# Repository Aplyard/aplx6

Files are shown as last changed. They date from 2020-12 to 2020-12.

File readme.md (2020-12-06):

# Aplx6 (rev2)

Top View 
An updated encoder version, implementing music, browser and document shortcuts. Designed to be assembled as a sandwich with a blank PCB, using M2.5 screws and spacers, your choice of MX- or Alps-compatible switches, and 1N4148 diodes.
## New features
* Encoder (with push button for cycling layers)
* Oled display for some fancy logos
* More layers

## New Layout  
|Default|Layer|(0)|
|--|--|--|
| Mute|Play|Fn & Vol +/-|
|Prev|Stop|Next|

<br />

| Fn |Layer|(1)
|--|--|--|
|Home|PgUp|Cursor|
|End|PgDown|Ins

<br />

| Fn |Layer|(2)
|--|--|--|
|Calc|MyPc|Brightness|
|Copy|Cut|Paste

## Firmware
Aplx6 uses [QMK Firmware](https://qmk.fm/)  
 
Make example for this keyboard (after setting up your build environment):

     make aplyard/aplx6/rev2:default

See the [build environment setup](https://docs.qmk.fm/#/getting_started_build_tools) and the [make instructions](https://docs.qmk.fm/#/getting_started_make_guide) for more information. Brand new to QMK? Start with our [Complete Newbs Guide](https://docs.qmk.fm/#/newbs).

## Info
* Keyboard Maintainer: [Aplyard](https://github.com/Aplyard)
* Hardware Supported: Aplx6 rev2 PCB, Pro Micro (ATmega32U4)
* Hardware Availability: [GitHub](https://github.com/Aplyard/Aplx6-rev2)

---  

****Designed in**:**  
[KiCad](https://github.com/KiCad)  

**Components Footprints & Libraries :**  
[MX_Alps_Hybrid](https://github.com/tyetye/MX_Alps_Hybrid.pretty)  
[keebs.pretty](https://github.com/egladman/keebs.pretty)  
[keyboard_parts.pretty
](https://github.com/tmk/keyboard_parts.pretty)  
[ProMicro KiCad](https://github.com/Biacco42/ProMicroKiCad) 

**Usefull Links:**  
[Qmk Online Configurator](https://config.qmk.fm/#)  
[Keyboard Layout Editor](http://www.keyboard-layout-editor.com/#/)   
[Keyboard Plate & Case Builder](http://builder.swillkb.com/)

---

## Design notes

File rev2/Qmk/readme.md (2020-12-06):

# Aplx6 rev2

Top View 
   
An updated encoder version, implementing music, browser and document shortcuts. Designed to be assembled as a sandwich with a blank PCB, using M2.5 screws and spacers, your choice of MX- or Alps-compatible switches, and 1N4148 diodes.

## New features
* Encoder (with push button for cycling layers)
* Oled display for some fancy logos
* More layers

## Firmware
* Keyboard Maintainer: [Aplyard](https://github.com/Aplyard)
* Hardware Supported: Aplx6 PCB, Pro Micro (ATmega32U4)
* Hardware Availability: [GitHub](https://github.com/Aplyard/aplx6/tree/master/rev2)

Make example for this keyboard (after setting up your build environment):

     make aplyard/aplx6/rev2:default

See the [build environment setup](https://docs.qmk.fm/#/getting_started_build_tools) and the [make instructions](https://docs.qmk.fm/#/getting_started_make_guide) for more information. Brand new to QMK? Start with our [Complete Newbs Guide](https://docs.qmk.fm/#/newbs).

---  
****Designed in**:**  
[KiCad](https://github.com/KiCad)  

**Components Footprints & Libraries :**  
[MX_Alps_Hybrid](https://github.com/tyetye/MX_Alps_Hybrid.pretty)  
[keebs.pretty](https://github.com/egladman/keebs.pretty)  
[keyboard_parts.pretty
](https://github.com/tmk/keyboard_parts.pretty)  
[ProMicro KiCad](https://github.com/Biacco42/ProMicroKiCad) 

**Usefull Links:**  
[Qmk Online Configurator](https://config.qmk.fm/#)  
[Keyboard Layout Editor](http://www.keyboard-layout-editor.com/#/)   
[Keyboard Plate & Case Builder](http://builder.swillkb.com/)

---

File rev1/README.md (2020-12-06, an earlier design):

# Aplx6
https://github.com/Aplyard/aplx6   
   
A stylish (2x3) 6-key MediaPad for your music and browser shortcuts.
Designed to be assembled as a sandwich with a blank pcb, using m2.5 screws and spacers. 
Diodes : 1N4148   

---

FrontEmpty   

Back

Front

---

**Can support Rgb underglow (WS2812)** 

Just wire them to any of the unused ProMicro pins.
Don't forget to edit-uncomment the [config.h](https://github.com/Aplyard/Aplx6/blob/master/qmk/config.h) and the [rules.mk](https://github.com/Aplyard/Aplx6/blob/master/qmk/rules.mk)
for RGB underglow support or even add your own functions and modes.
Used pins can be found in [config.h](https://github.com/Aplyard/Aplx6/blob/master/qmk/config.h) or in the [KiCad Schematic](https://github.com/Aplyard/Aplx6/blob/master/kiCad/xd6.sch)
All ProMicro pins can be found [here](https://golem.hu/article/pro-micro-pinout/) along with the +2 pins mod.

---

**Default Keymap Layout is [Media](https://github.com/Aplyard/Aplx6/blob/master/qmk/keymaps/Media/keymap.c)** (no RGB shortcuts)

|Default|Layer|(0)|
|--|--|--|
| Play|VolUp|Fn|
|Prev|VolDown|Next|

=========================
| Fn |Layer|(1)
|--|--|--|
|Calc|PgUp|KC_TRANS|
|MyPc|PgDown|RESET

---

Make example for this keyboard (after setting up your build environment):

     make aplyard/aplx6/rev1:default

See [build environment setup](https://docs.qmk.fm/#/getting_started_build_tools) then the [make instructions](https://docs.qmk.fm/#/getting_started_make_guide) for more information.

---  
****Designed in**:**  
[KiCad](https://github.com/KiCad)  

**Components Footprints & Libraries :**  
[keebs.pretty](https://github.com/egladman/keebs.pretty)  
[keyboard_parts.pretty
](https://github.com/tmk/keyboard_parts.pretty)  
[ProMicro KiCad](https://github.com/Biacco42/ProMicroKiCad)  

**Usefull Links:**  
[Qmk Online Configurator](https://config.qmk.fm/#)  

**Alternatives of qmk that worked for me:**  
[Keyboard Layout Editor](http://www.keyboard-layout-editor.com/#/)   
[Keyboard Plate & Case Builder](http://builder.swillkb.com/)  
[Firmware Builder](https://kbfirmware.com/)      

---   
Keyboard Maintainer: Aplyard  
Hardware Supported: Pro Micro ATmega32U4  
Hardware Availability: Aplyard

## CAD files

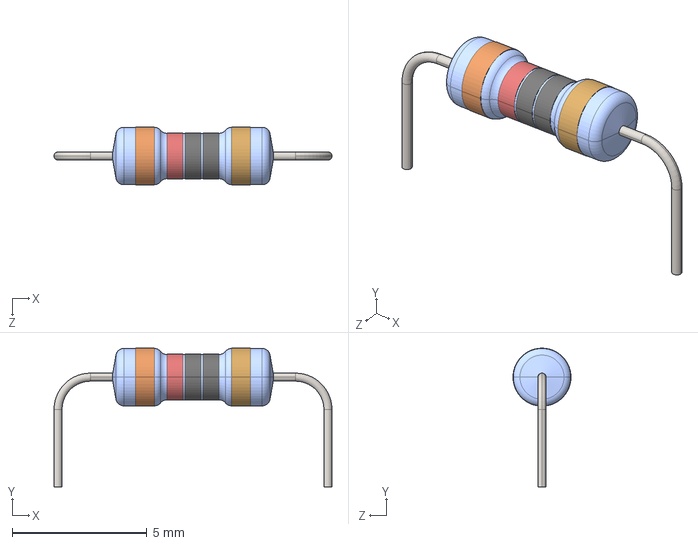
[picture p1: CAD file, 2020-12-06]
rev2/Pcb/3dModels/axial resistor 6mm.STEP
10.3 x 5.14 x 2.15 mm

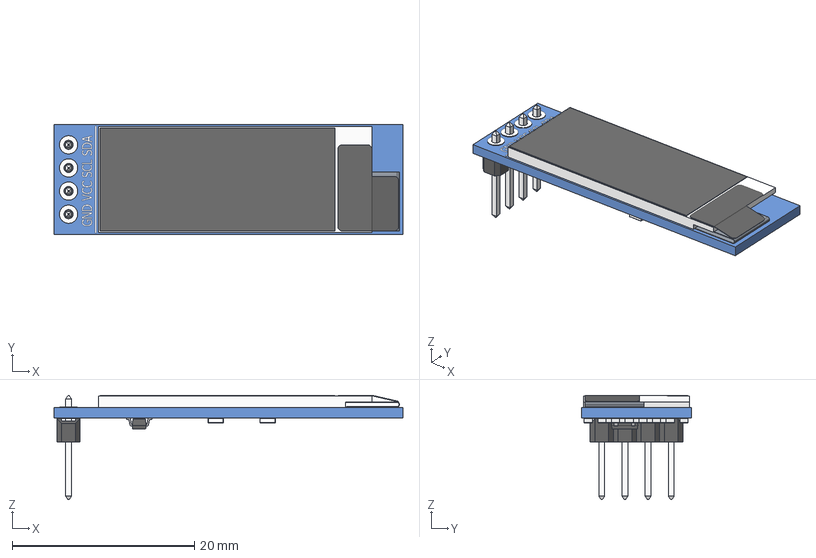
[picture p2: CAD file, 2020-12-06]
rev2/Pcb/3dModels/OLED_0.91_128x32.stp
38.3 x 12.1 x 11.5 mm
OLED_0.91_128x32
Pin Header 4 x 1 TH 2.54mm Pitch
RESC-0603 x 13
2SD0601A

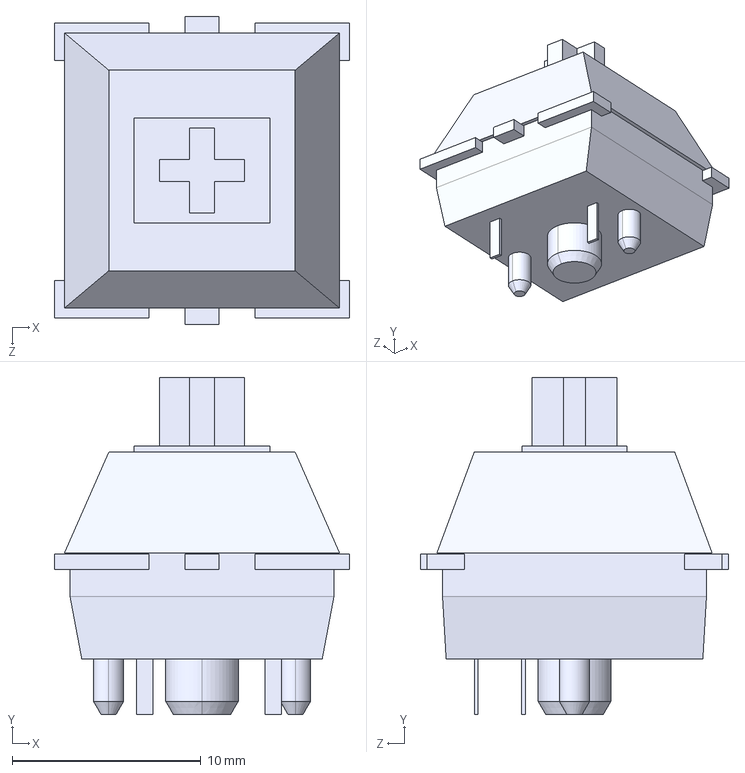
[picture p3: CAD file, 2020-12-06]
rev2/Pcb/3dModels/cherry mx.STEP
15.6 x 17.9 x 16.3 mm

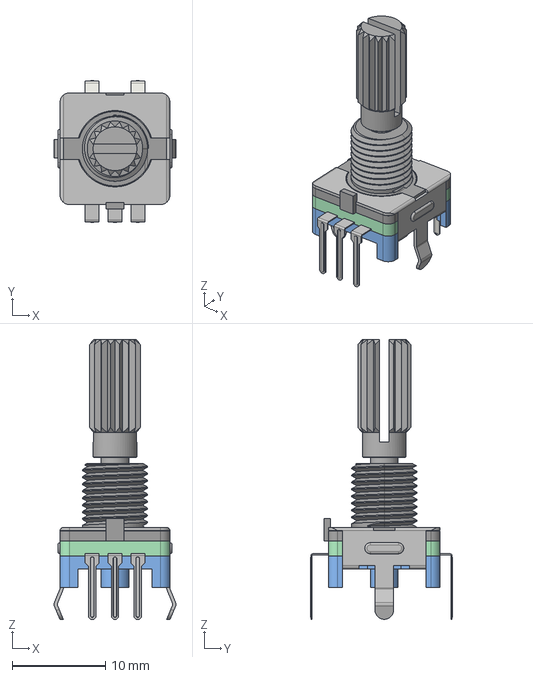
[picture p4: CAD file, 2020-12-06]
rev2/Pcb/3dModels/EC11_Rotary_Encoder_Switched.step
13.1 x 15.3 x 30.1 mm

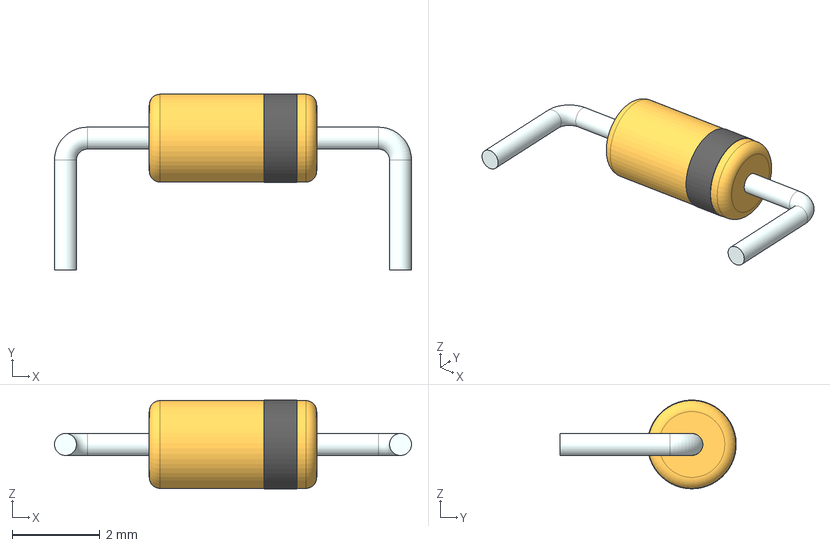
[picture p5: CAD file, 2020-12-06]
rev2/Pcb/3dModels/Diode DO-35 300 mil.step
8.12 x 4.01 x 2.02 mm

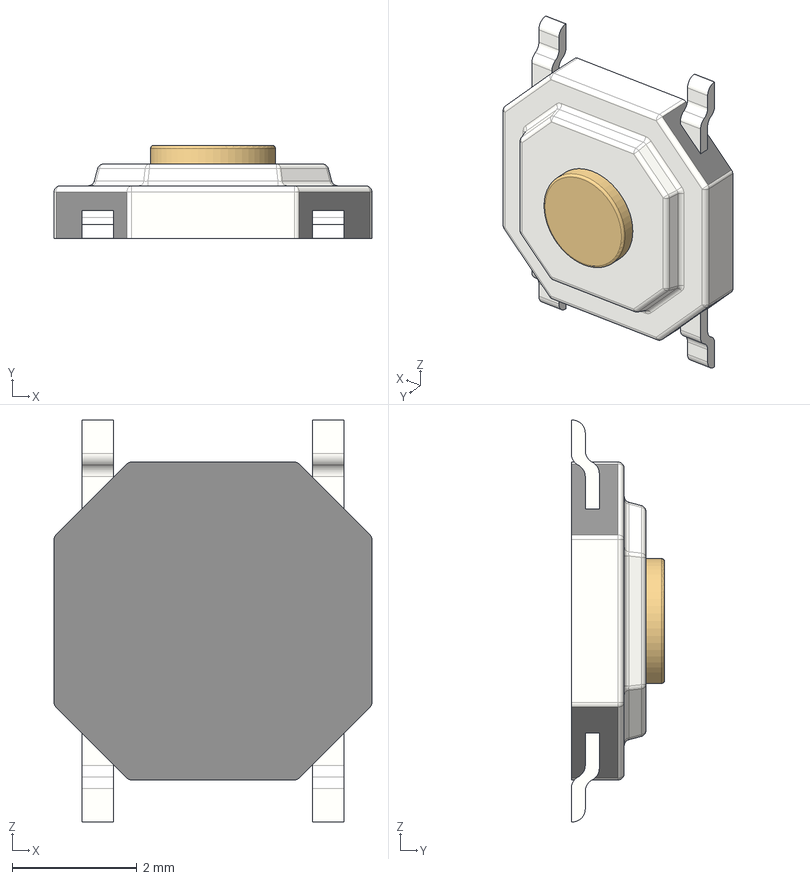
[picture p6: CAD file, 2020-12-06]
rev2/Pcb/3dModels/TactileButton(5mm)_SMD.stp
5.10 x 1.50 x 6.45 mm

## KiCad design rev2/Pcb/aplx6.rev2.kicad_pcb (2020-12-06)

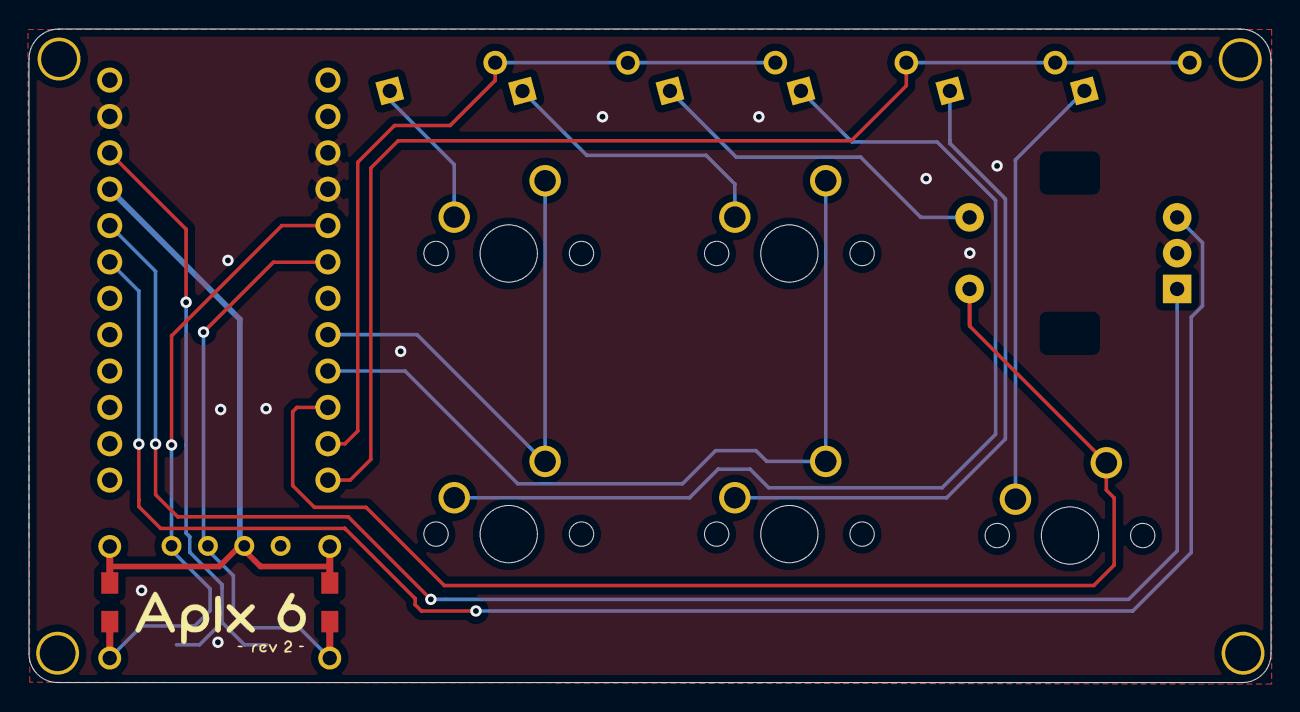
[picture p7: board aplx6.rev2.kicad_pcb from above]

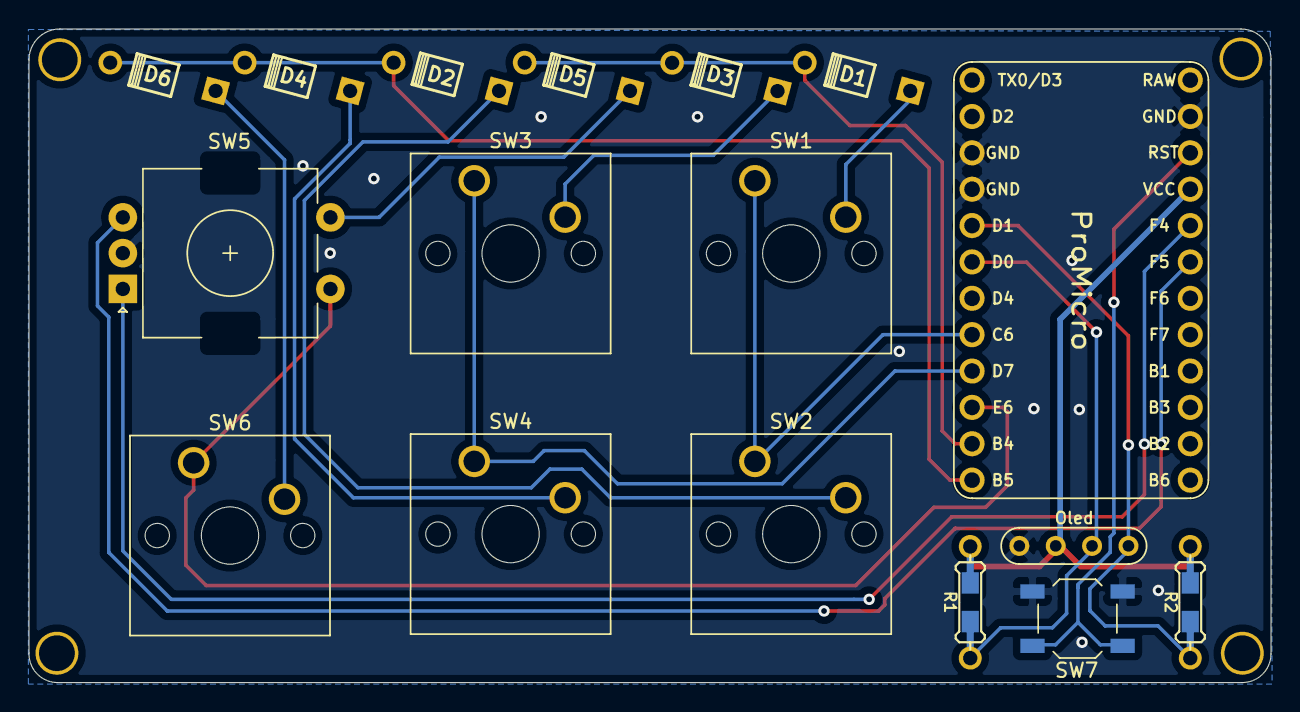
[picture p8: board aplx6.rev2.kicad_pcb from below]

Board: 2 copper layers, 86.8 x 45.7 mm, 21 parts (3 on the bottom side), 18 nets.

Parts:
D1, D2, D3, D4, D5, D6: D; Diode
J1: Oled; OLED
R1, R2: 4,7; Resistor-Hybrid
SW1, SW2, SW3, SW4, SW6: MX-NoLED; SW_Cherry_MX_1.00u_PCB
SW5: Rotary_Encoder_Switch; RotaryEncoder_EC11
SW7: SW_DIP_x02; SW_SPST_TL3342
U1: ProMicro; ArduinoProMicro
U4, U4#2, U4#3, U4#4: HOLE; MountingHole

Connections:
ENC_A: SW5.A, U1.20
ENC_B: SW5.B, U1.19
GND: J1.4, SW5.C, SW7.1, SW7.2, U1.3, U1.4, U1.23
unnamed: D1.2, SW1.2
unnamed: D2.2, SW2.2
unnamed: D3.2, SW3.2
unnamed: D4.2, SW4.2
unnamed: D5.2, SW5.S1
unnamed: D6.2, SW6.2
RESET: SW7.3, SW7.4, U1.22
SCL: J1.2, R1.2, U1.6
SDA: J1.1, R2.2, U1.5
VCC: J1.3, R1.1, R2.1, U1.21
col0: SW1.1, SW2.1, U1.8
col1: SW3.1, SW4.1, U1.9
col2: SW5.S2, SW6.1, U1.10
row0: D1.1, D3.1, D5.1, U1.11
row1: D2.1, D4.1, D6.1, U1.12

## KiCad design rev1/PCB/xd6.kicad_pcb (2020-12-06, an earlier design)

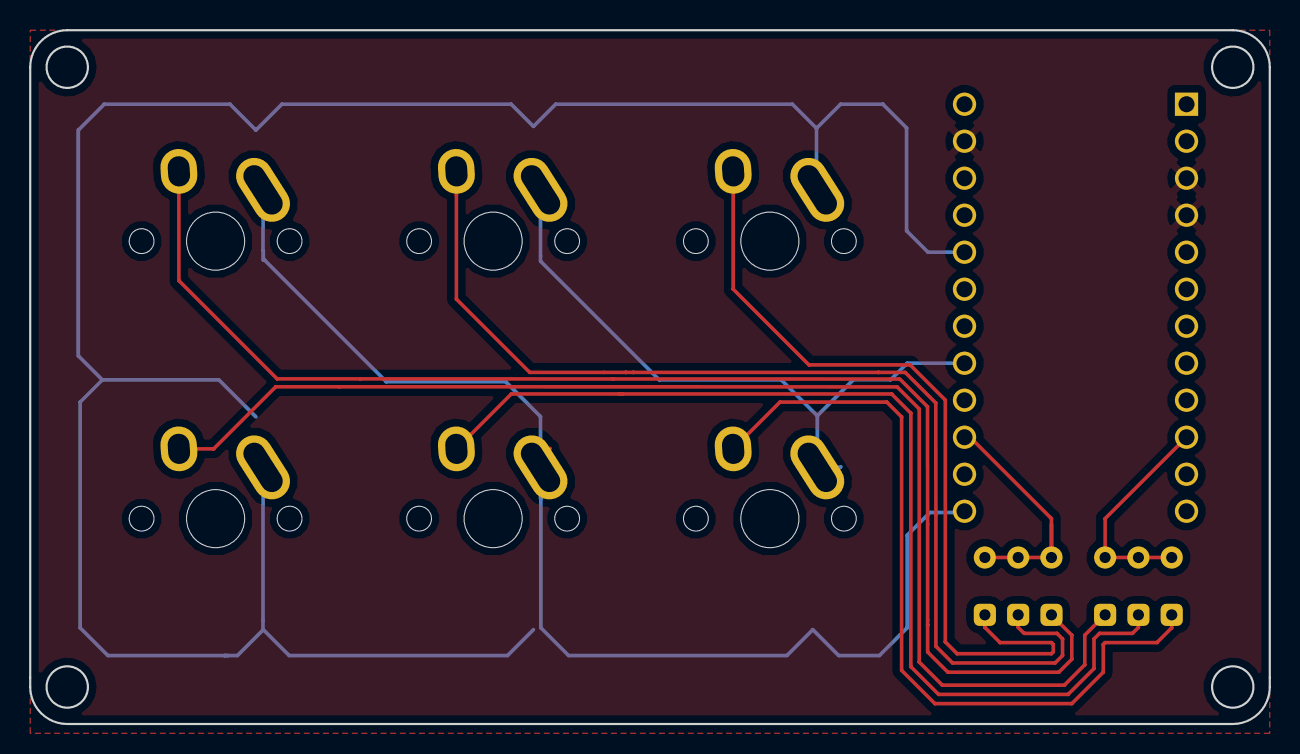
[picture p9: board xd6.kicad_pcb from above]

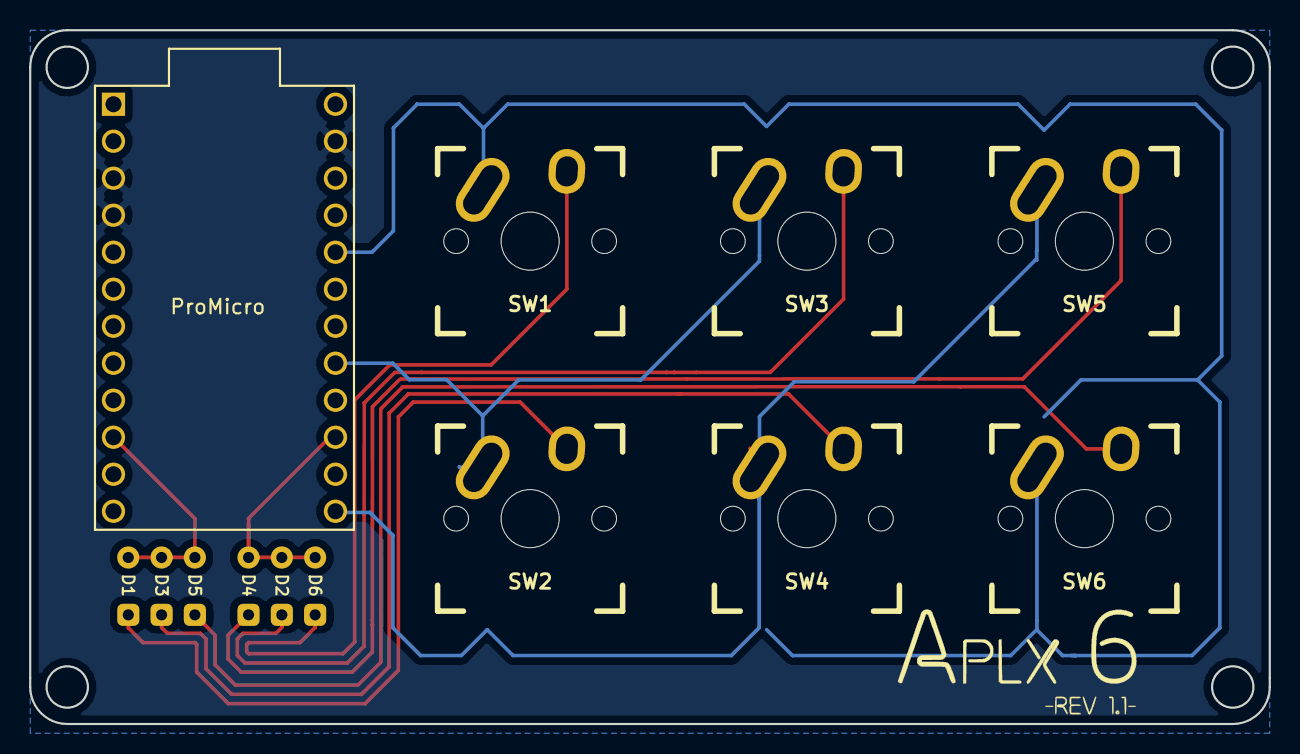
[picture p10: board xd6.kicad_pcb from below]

Board: 2 copper layers, 85.1 x 47.6 mm, 17 parts (7 on the bottom side), 12 nets.

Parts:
D1, D2, D3, D4, D5, D6: D_SOD123_axial_APLYARD
HOLE_M2.6, HOLE_M2.6#2, HOLE_M2.6#3, HOLE_M2.6#4: m2.6; HOLE_M2.6
SW1, SW2, SW3, SW4, SW5, SW6: KEYSW; Mx_Alps_100
U1: ProMicro; ProMicro1

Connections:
/Col0: SW2.1, SW3.1, U1.17
/Col1: SW4.1, SW5.1, U1.13
/Col2: SW1.1, SW6.1, U1.20
/row0: D1.1, D3.1, D5.1, U1.10
/row1: D2.1, D4.1, D6.1, U1.15
GND: U1.3, U1.4, U1.23
unnamed: D1.2, SW2.2
unnamed: D2.2, SW3.2
unnamed: D3.2, SW4.2
unnamed: D4.2, SW5.2
unnamed: D5.2, SW6.2
unnamed: D6.2, SW1.2

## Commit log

2020-12-06 rev 1
    [blank.kicad_pcb, xd6.kicad_pcb, xd6.sch]
2020-12-06 rev 2
    [Diode DO-35 300 mil.step, EC11_Rotary_Encoder_Switched.step, OLED_0.91_128x32.stp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]
